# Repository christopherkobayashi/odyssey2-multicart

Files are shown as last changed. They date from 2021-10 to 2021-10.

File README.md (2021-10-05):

# Simple Odyssey2/Videopac multicart

This is a simple manually-switched Odyssey2/Videopac multicart.  DIP switches select from one of 32 cartridge banks.

The hardware design is not mine.  It is courtesy
[Wilco2008's blog](https://web.archive.org/web/20210601074542/https://wilco2009.blogspot.com/2018/09/videopac-multirom-cart-version-1.html).

The multicart Eagle schematic and board files are in the eagle/ subdirectory.  Gerber files suitable for fabrication from PCBway are in the gerber/ subdirectory.

The EEPROM is a Winbond 29C040, which are readily available on the secondary market.  The resisters are typical 1/4 watt pulldowns; I used 4.7k because I had them lying around.  The capacitor is a 0.1uF non-polarized ceramic.

Wilco2008 provided a Windows binary to convert o2em ROM files into 16k images suitable for each bank.  Unfortunately, the binary doesn't work (it appears to FTP to a site that doesn't exist anymore, and then quits immediately).  Source code is unavailable.

Happily, the ROM memory layout is documented in this post at the
[Videopac Forum](http://videopac.nl/forum/index.php?topic=1778.0).  The python script `prep-16k.py` will assemble a bank-switched image from an input file.

The code from the forum post is below.

```
	nb=size/1024;  // find out number of kbytes to load

        switch (nb){
            case 2: // 2 k cartridge no A10
                    printf("Loading %d blocks of 1k\n\r",nb);

                    fread(&rom_buffer[0x0400],2048,1,fp);                       // read 2k block at 0x0400
                    memcpy(&rom_buffer[0x0c00],&rom_buffer[0x0800],1024);       // mirror to 0x0C00 (ignore A10)           
                    
                    memcpy(&rom_buffer[0x1000],&rom_buffer[0x0000],4096);       // mirror (ignore P10)
                    memcpy(&rom_buffer[0x2000],&rom_buffer[0x0000],8192);       // mirror (ignore P11)

                    break;
            case 4: // 4 k cartridge no A10, ROM_A11=CPU_P10, ROM_A10=CPU_A11 ignore P11
                    // after RESET P10 (and P11) will be high so a fetch from the CPU 
                    // from 0x0400 will be from physical (EP)ROM address 0x0800
                    printf("Loading %d blocks of 1k\n\r",nb);

                    fread(&rom_buffer[0x0400],2048,1,fp);                       // read 2k block at 0x0400
                    memcpy(&rom_buffer[0x0C00],&rom_buffer[0x0800],1024);       // mirror to 0x0C00 (ignore A10)           

                    fread(&rom_buffer[0x1400],2048,1,fp);                       // read 2k block at 0x1400 
                    memcpy(&rom_buffer[0x1C00],&rom_buffer[0x1800],1024);       // mirror to 0x1C00 (ignore A10)    
                    
                    memcpy(&rom_buffer[0x2000],&rom_buffer[0x0000],8192);       // mirror (ignore P11)
                    
                    break;
            case 8: // 8 k cartridge no A10 bank select with P10 and P11 (A12 and A13)
                    fread(&rom_buffer[0x0400],2048,1,fp);                       // read 2k block at 0x0400
                    memcpy(&rom_buffer[0x0C00],&rom_buffer[0x0800],1024);       // mirror to 0x0C00 (ignore A10)           

                    fread(&rom_buffer[0x1400],2048,1,fp);                       // read 2k block at 0x1400 
                    memcpy(&rom_buffer[0x1C00],&rom_buffer[0x1800],1024);       // mirror to 0x1C00 (ignore A10)   

                    fread(&rom_buffer[0x2400],2048,1,fp);                       // read 2k block at 0x2400
                    memcpy(&rom_buffer[0x2C00],&rom_buffer[0x2800],1024);       // mirror to 0x2C00 (ignore A10)           

                    fread(&rom_buffer[0x3400],2048,1,fp);                       // read 2k block at 0x3400 
                    memcpy(&rom_buffer[0x3C00],&rom_buffer[0x3800],1024);       // mirror to 0x3C00 (ignore A10)   
                    
                    break;
            default:// unknown size
                    printf("Panic!\n\rUnknown rom size\n\r");
                    break;
        }
```

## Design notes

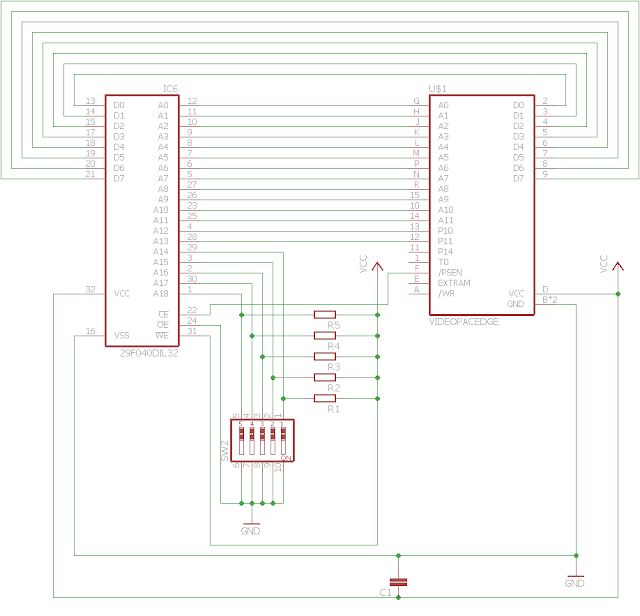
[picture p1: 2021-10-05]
schematic.png

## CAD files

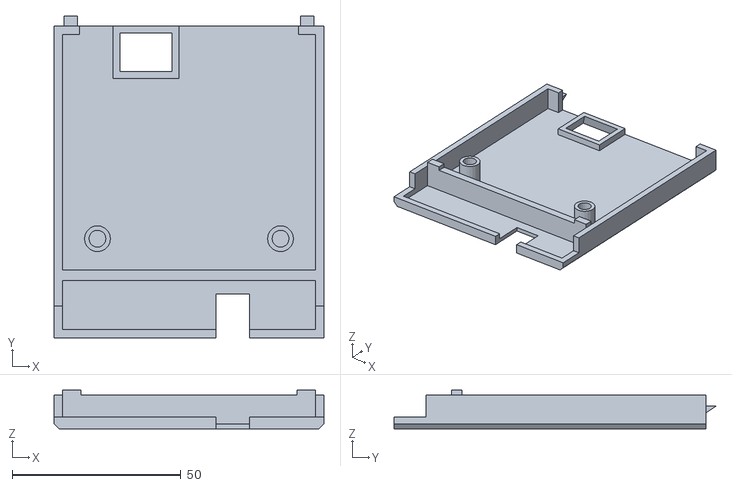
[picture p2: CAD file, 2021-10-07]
case/Videopac_-_TOP_Multirom_Cart_v1.1_Wilco2009.stl
80.0 x 95.5 x 11.5

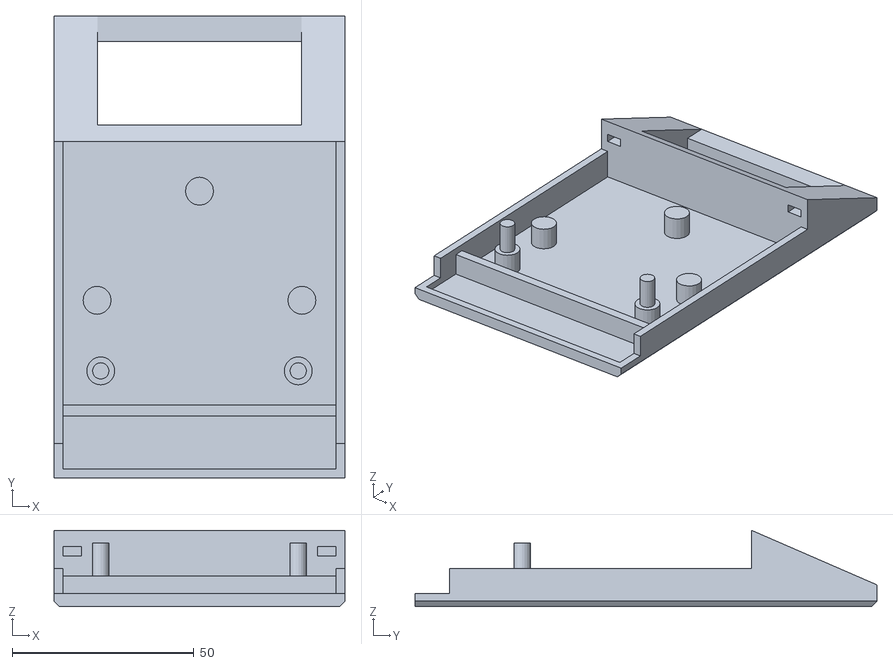
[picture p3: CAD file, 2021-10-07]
case/Videopac_-_BOTTOM.stl
80.0 x 127.0 x 21.0

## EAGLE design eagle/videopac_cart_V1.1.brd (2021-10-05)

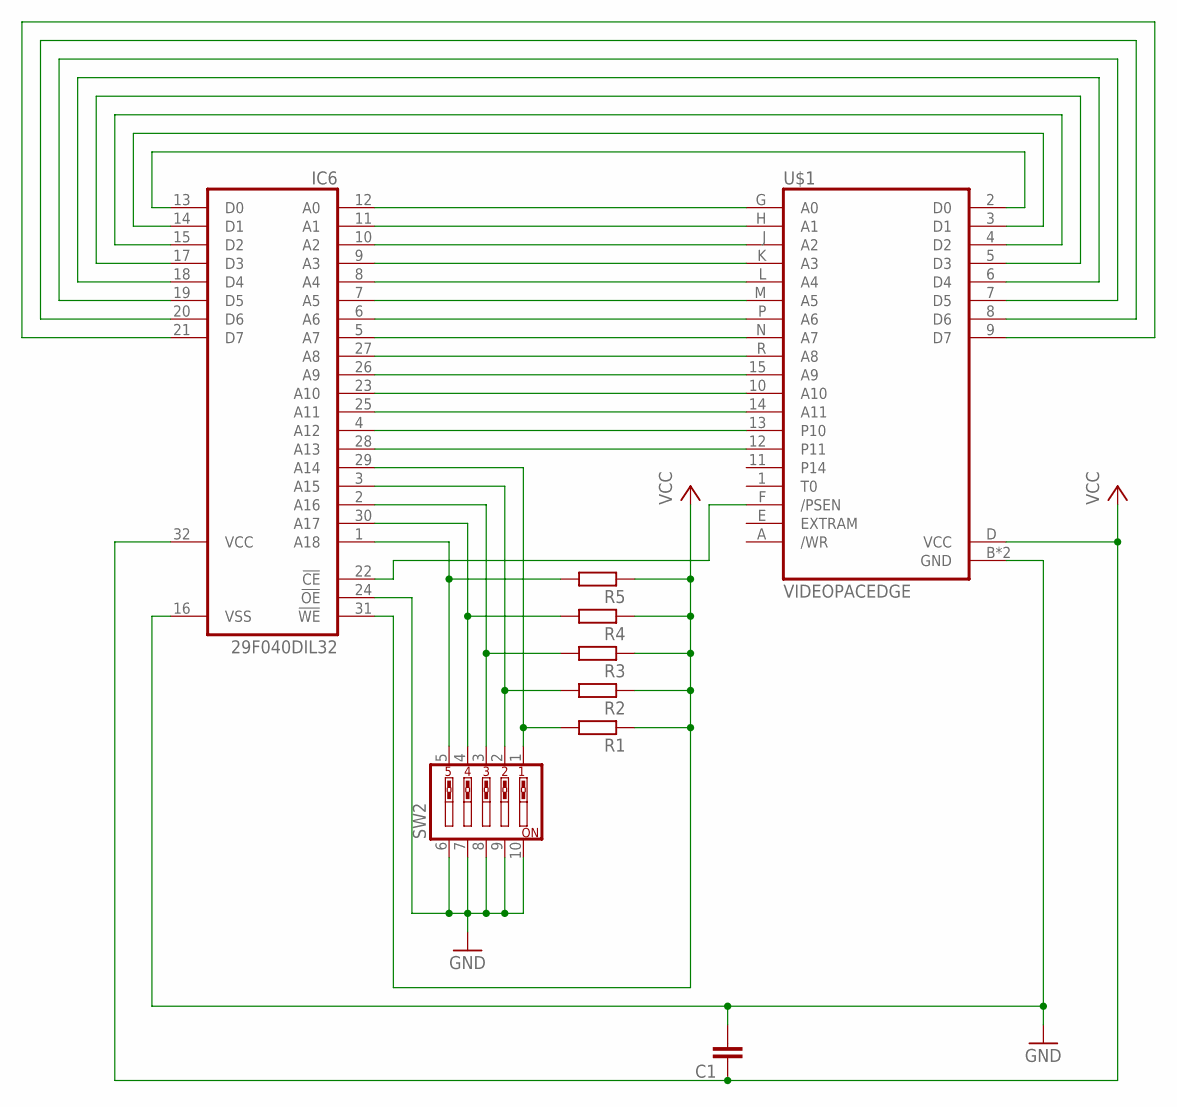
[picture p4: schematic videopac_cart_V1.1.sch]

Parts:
C1: C-EU025-030X050; C025-030X050
IC6: 29F040DIL32; DIL32
R1, R2, R3, R4, R5: R-EU_0207/10; 0207/10
SW2: SW_DIP-5; EDG-05
U$1: VIDEOPACEDGE; VIDEOPAC

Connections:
GND: C1.2, IC6.16 (VSS), IC6.24 (!OE), SW2.6, SW2.7, SW2.8, SW2.9, SW2.10, U$1.B (GND), U$1.C (GND)
unnamed: IC6.12 (A0), U$1.G (A0)
unnamed: IC6.11 (A1), U$1.H (A1)
unnamed: IC6.10 (A2), U$1.J (A2)
unnamed: IC6.9 (A3), U$1.K (A3)
unnamed: IC6.8 (A4), U$1.L (A4)
unnamed: IC6.7 (A5), U$1.M (A5)
unnamed: IC6.6 (A6), U$1.P (A6)
unnamed: IC6.5 (A7), U$1.N (A7)
unnamed: IC6.27 (A8), U$1.R (A8)
unnamed: IC6.26 (A9), U$1.15 (A9)
unnamed: IC6.23 (A10), U$1.10 (A10)
unnamed: IC6.25 (A11), U$1.14 (A11)
unnamed: IC6.4 (A12), U$1.13 (P10)
unnamed: IC6.28 (A13), U$1.12 (P11)
unnamed: IC6.29 (A14), R1.2, SW2.1
unnamed: IC6.3 (A15), R2.2, SW2.2
unnamed: IC6.2 (A16), R3.2, SW2.3
unnamed: IC6.30 (A17), R4.2, SW2.4
unnamed: IC6.1 (A18), R5.2, SW2.5
unnamed: IC6.22 (!CE), U$1.F (/PSEN)
unnamed: IC6.13 (D0), U$1.2 (D0)
unnamed: IC6.14 (D1), U$1.3 (D1)
unnamed: IC6.15 (D2), U$1.4 (D2)
unnamed: IC6.17 (D3), U$1.5 (D3)
unnamed: IC6.18 (D4), U$1.6 (D4)
unnamed: IC6.19 (D5), U$1.7 (D5)
unnamed: IC6.20 (D6), U$1.8 (D6)
unnamed: IC6.21 (D7), U$1.9 (D7)
VCC: C1.1, IC6.31 (!WE), IC6.32 (VCC), R1.1, R2.1, R3.1, R4.1, R5.1, U$1.D (VCC)

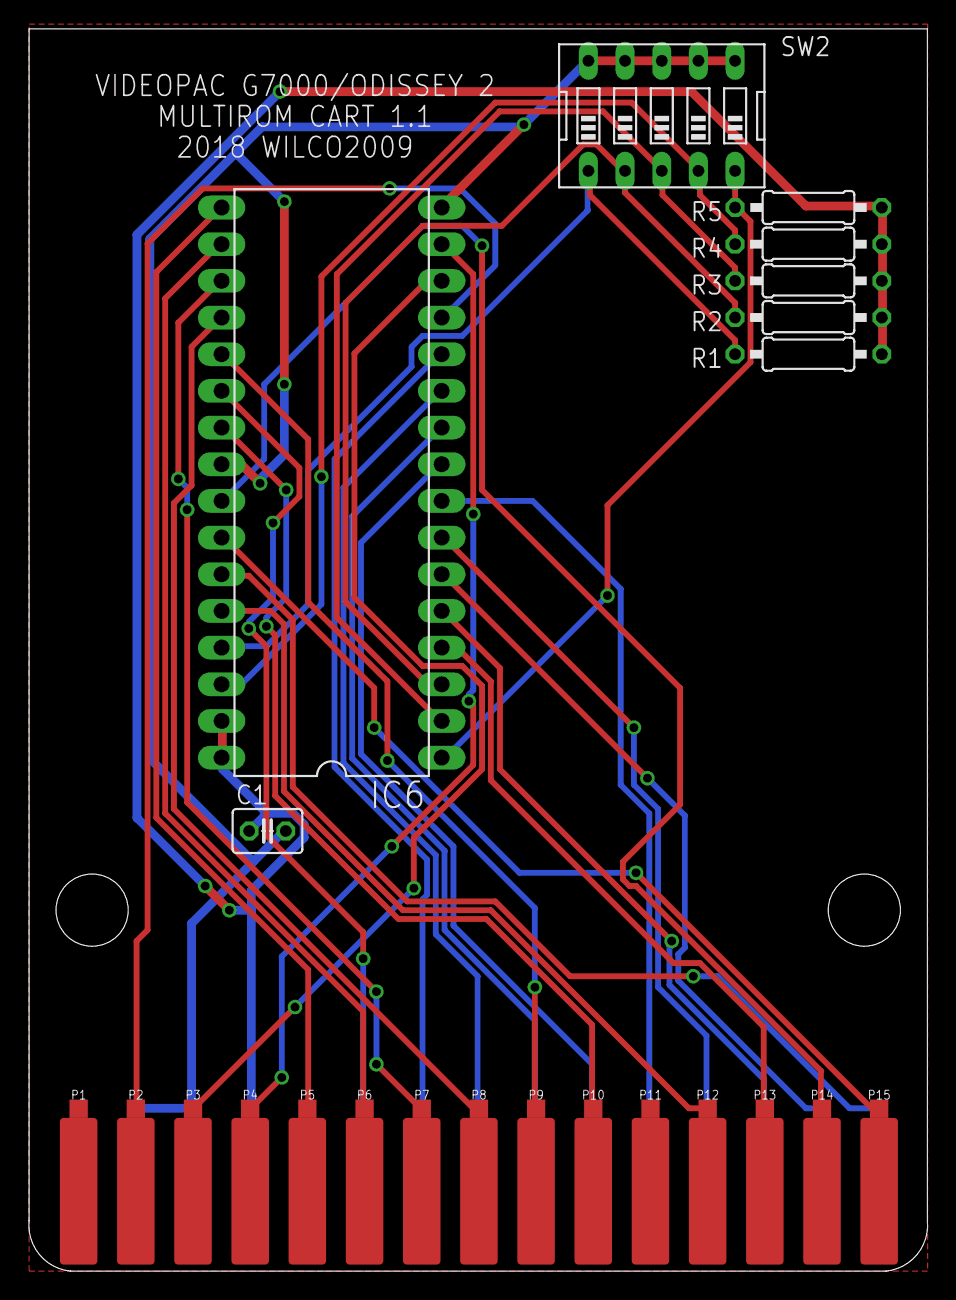
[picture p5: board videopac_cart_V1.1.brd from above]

Board: 2 copper layers, 62.2 x 86.0 mm, 9 parts (0 on the bottom side), 30 nets.

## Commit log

2021-10-05 Initial import.
    [videopac_cart_V1.1.GBL, videopac_cart_V1.1.GBO, videopac_cart_V1.1.GBP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]
2021-10-07 Add STL files for case.
    [Videopac_-_BOTTOM.stl, Videopac_-_TOP_Multirom_Cart_v1.1_Wilco2009.stl]
